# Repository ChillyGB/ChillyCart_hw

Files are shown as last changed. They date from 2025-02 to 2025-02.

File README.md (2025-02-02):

# ChillyCart (hardware)


A simple rp2350 based gameboy(color) cartdrige complete with:
- SPI SD card
- RTC 
- Accelerometer
- 8 MB of PSRAM

## ⚠️ Warning: untested design, DO NOT USE

| Parameter | Value |
|---|---|
| PCB Layers | 2 |
| Surface Finish  | ENIG(w/ gold fingers) |
| Board Thickness | 1.0mm |
| Meow | prrrr |

## TODO: 
- *Test if the design actually works and doesn't blow up*
- Route power and PSRAM/flash data lines in a cleaner way
- Provide BOM ( and cost optimize some components )

## Soures of inspiration 
- [kicad-gamepaks](https://github.com/djedditt/kicad-gamepaks) - cartrdge connector and edge cuts
- [Croco Cartridge](https://github.com/shilga/rp2040-gameboy-cartridge) - voltage translator
- [SummerCart](https://github.com/Polprzewodnikowy/SummerCart64) - RTC and power mux

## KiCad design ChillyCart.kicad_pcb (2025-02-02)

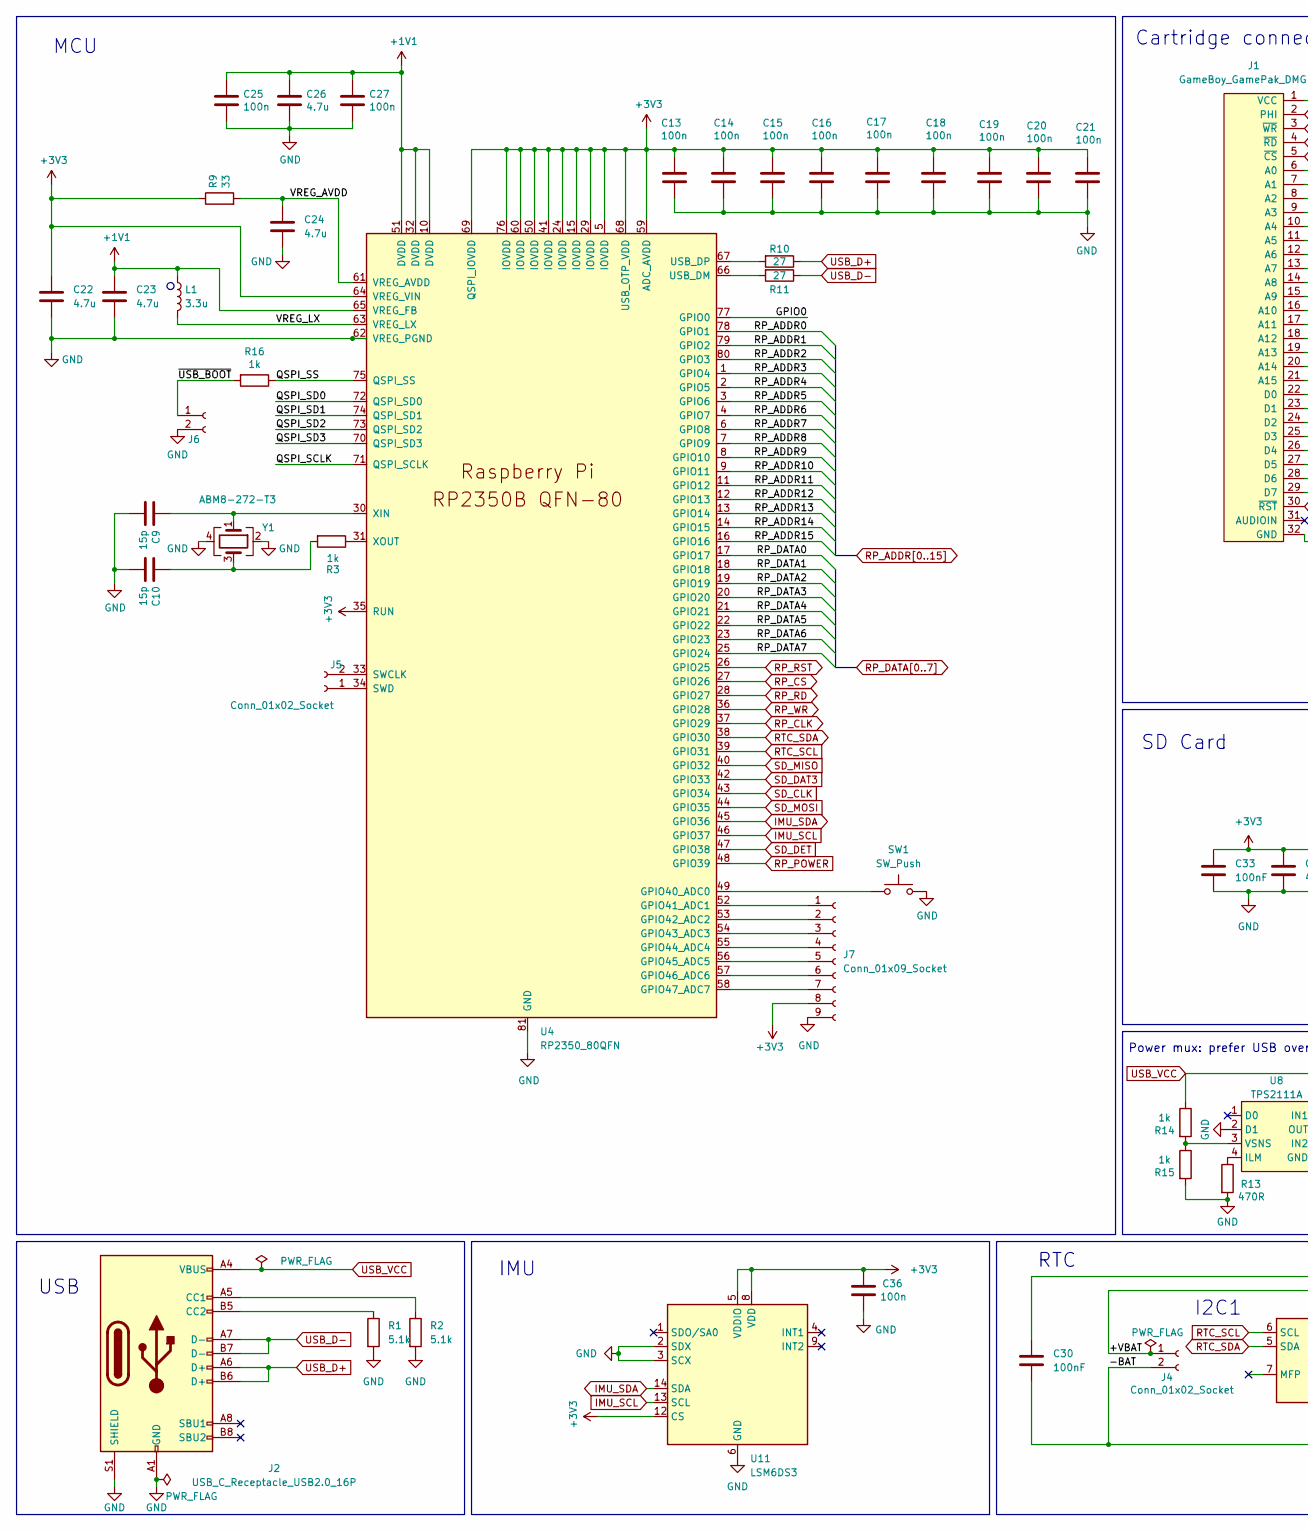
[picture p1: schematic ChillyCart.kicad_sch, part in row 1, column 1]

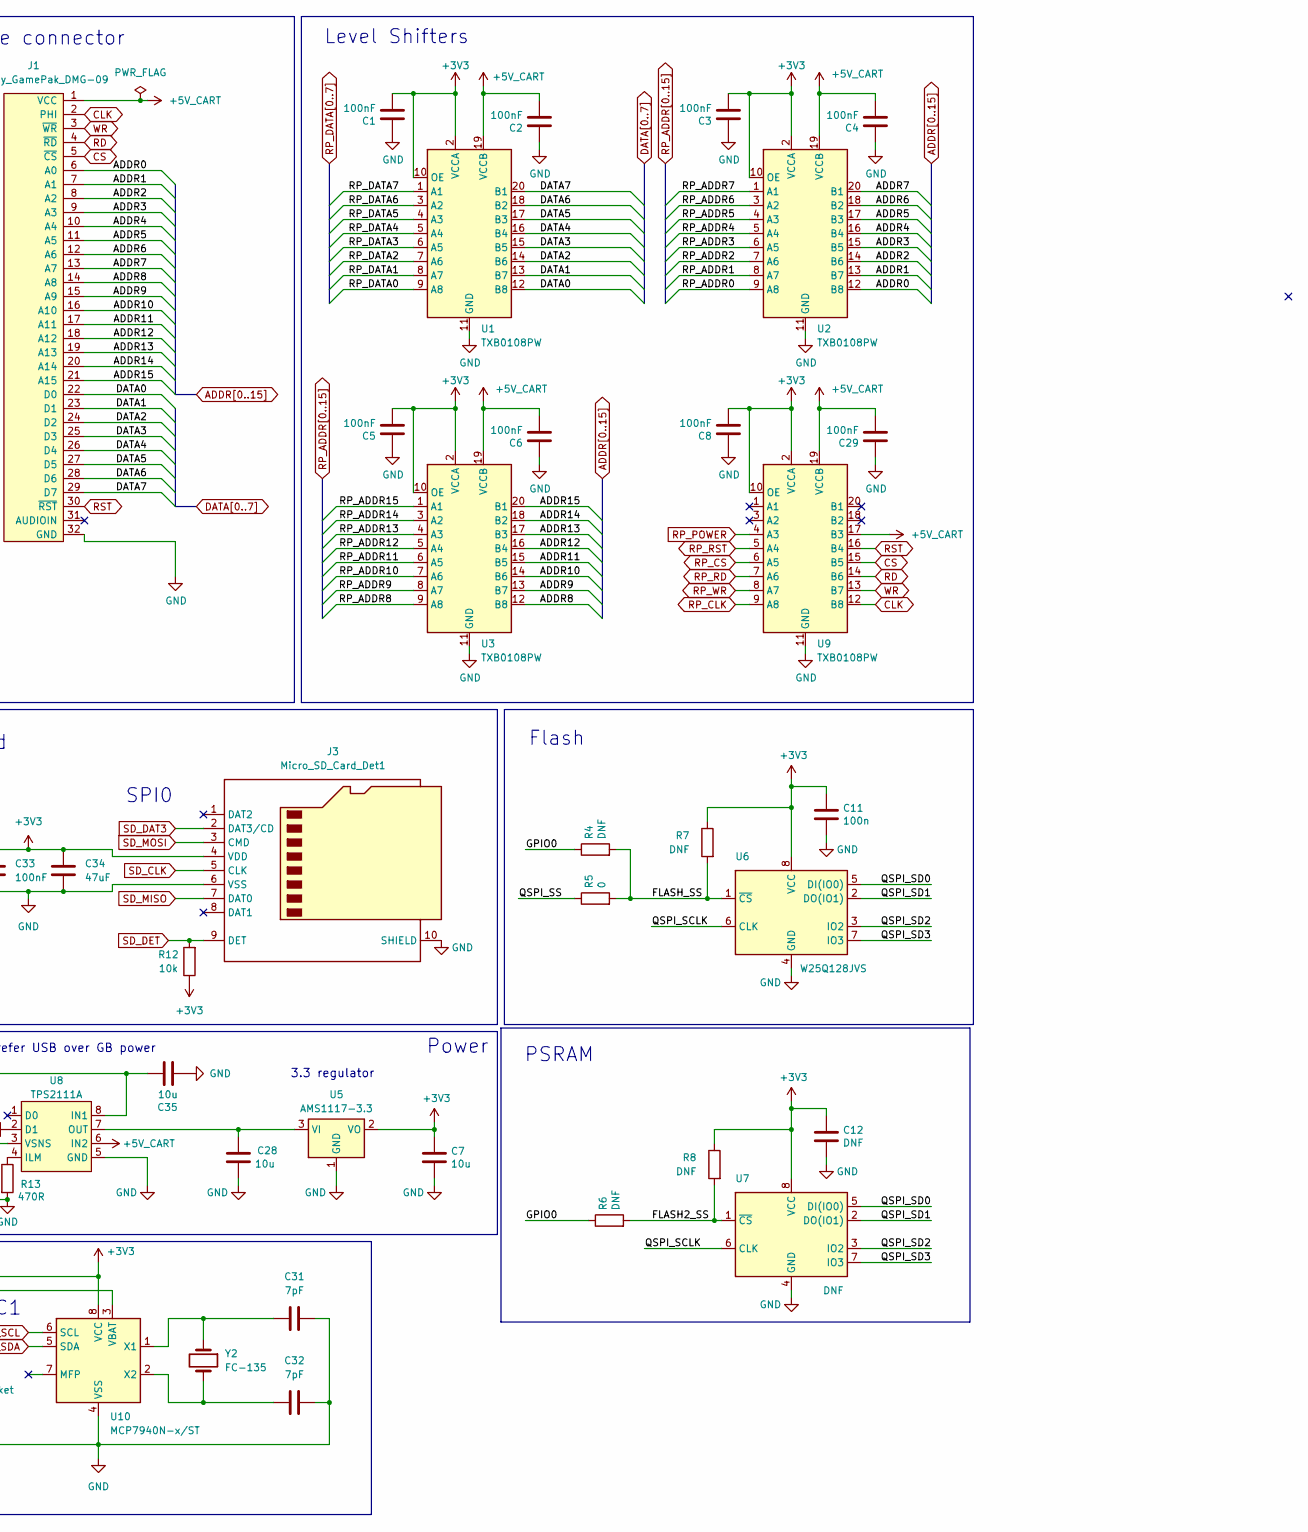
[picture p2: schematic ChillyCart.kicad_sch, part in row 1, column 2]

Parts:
C1, C2, C3, C4, C5, C6, C8, C29, C30, C33: 100nF; C_0402_1005Metric_Pad0.74x0.62mm_HandSolder
C7, C28, C35: 10u; C_0402_1005Metric_Pad0.74x0.62mm_HandSolder
C9, C10: 15p; C_0402_1005Metric_Pad0.74x0.62mm_HandSolder
C11, C13, C14, C15, C16, C17, C18, C19, C20, C21, C25, C27, C36: 100n; C_0402_1005Metric_Pad0.74x0.62mm_HandSolder
C12: DNF; C_0402_1005Metric_Pad0.74x0.62mm_HandSolder
C22, C23, C24, C26: 4.7u; C_0402_1005Metric_Pad0.74x0.62mm_HandSolder
C31, C32: 7pF; C_0402_1005Metric_Pad0.74x0.62mm_HandSolder
C34: 47uF; C_0402_1005Metric_Pad0.74x0.62mm_HandSolder
J1: GameBoy_GamePak_DMG-09; GameBoy_GamePak_DMG-09_P1.50mm_Edge
J2: USB_C_Receptacle_USB2.0_16P; USB_C_Receptacle_G-Switch_GT-USB-7010ASV
J3: Micro_SD_Card_Det1; TF-015
J4, J5, J6: Conn_01x02_Socket; TestPoint_2Pads_Pitch2.54mm_Drill0.8mm
J7: Conn_01x09_Socket; PinHeader_1x09_P1.00mm_Vertical
L1: 3.3u; L_pol_2016
R1, R2: 5.1k; R_0402_1005Metric_Pad0.72x0.64mm_HandSolder
R3, R14, R15, R16: 1k; R_0402_1005Metric_Pad0.72x0.64mm_HandSolder
R4, R6, R7, R8: DNF; R_0402_1005Metric_Pad0.72x0.64mm_HandSolder
R5: 0; R_0402_1005Metric_Pad0.72x0.64mm_HandSolder
R9: 33; R_0402_1005Metric_Pad0.72x0.64mm_HandSolder
R10, R11: 27; R_0402_1005Metric_Pad0.72x0.64mm_HandSolder
R12: 10k; R_0402_1005Metric_Pad0.72x0.64mm_HandSolder
R13: 470R; R_0402_1005Metric_Pad0.72x0.64mm_HandSolder
SW1: SW_Push; SW_Push_1P1T_XKB_TS-1187A
U1, U2, U3, U9: TXB0108PW; TSSOP-20_4.4x6.5mm_P0.65mm; LCSC C53406
U4: RP2350_80QFN; RP2350-QFN-80-1EP_10x10_P0.4mm_EP3.4x3.4mm_ThermalVias
U5: AMS1117-3.3; SOT-223-3_TabPin2
U6: W25Q128JVS; SOIC-8_5.23x5.23mm_P1.27mm
U7: DNF; SOIC-8_5.23x5.23mm_P1.27mm
U8: TPS2111A; TSSOP-8_4.4x3mm_P0.65mm
U10: MCP7940N-x/ST; TSSOP-8_4.4x3mm_P0.65mm
U11: LSM6DS3; LGA-14_3x2.5mm_P0.5mm_LayoutBorder3x4y
Y1: ABM8-272-T3; Crystal_SMD_3225-4Pin_3.2x2.5mm
Y2: FC-135; Crystal_SMD_3215-2Pin_3.2x1.5mm

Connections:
+1V1: C23.1, C25.1, C26.1, C27.1, L1.1, U4.10 (DVDD), U4.32 (DVDD), U4.51 (DVDD), U4.65 (VREG_FB)
+3V3: C1.2, C3.2, C5.2, C7.1, C8.2, C11.1, C12.1, C13.1, C14.1, C15.1, C16.1, C17.1, C18.1, C19.1, C20.1, C21.1, C22.1, C30.1, C33.1, C34.1, C36.1, J3.4 (VDD), J7.8, R7.1, R8.1, R9.1, R12.1, U1.2 (VCCA), U1.10 (OE), U2.2 (VCCA), U2.10 (OE), U3.2 (VCCA), U3.10 (OE), U4.5 (IOVDD), U4.15 (IOVDD), U4.24 (IOVDD), U4.29 (IOVDD), U4.35 (RUN), U4.41 (IOVDD), U4.50 (IOVDD), U4.59 (ADC_AVDD), U4.60 (IOVDD), U4.64 (VREG_VIN), U4.68 (USB_OTP_VDD), U4.69 (QSPI_IOVDD), U4.76 (IOVDD), U5.2 (VO), U6.8 (VCC), U7.8 (VCC), U9.2 (VCCA), U9.10 (OE), U10.8 (VCC), U11.5 (VDDIO), U11.8 (VDD), U11.12 (CS)
+5V_CART: C2.2, C4.2, C6.2, C29.2, J1.1 (VCC), U1.19 (VCCB), U2.19 (VCCB), U3.19 (VCCB), U8.6 (IN2), U9.17 (B3), U9.19 (VCCB)
/+VBAT: J4.1, U10.3 (VBAT)
/FLASH2_SS: R6.2, R8.2, U7.1 (~CS)
/FLASH_SS: R4.2, R5.2, R7.2, U6.1 (~CS)
/GPIO0: R4.1, R6.1, U4.77 (GPIO0)
/QSPI_SCLK: U4.71 (QSPI_SCLK), U6.6 (CLK), U7.6 (CLK)
/QSPI_SD0: U4.72 (QSPI_SD0), U6.5 (DI(IO0)), U7.5 (DI(IO0))
/QSPI_SD1: U4.74 (QSPI_SD1), U6.2 (DO(IO1)), U7.2 (DO(IO1))
/QSPI_SD2: U4.73 (QSPI_SD2), U6.3 (IO2), U7.3 (IO2)
/QSPI_SD3: U4.70 (QSPI_SD3), U6.7 (IO3), U7.7 (IO3)
/QSPI_SS: R5.1, R16.1, U4.75 (QSPI_SS)
/VREG_AVDD: C24.1, R9.2, U4.61 (VREG_AVDD)
/VREG_LX: L1.2, U4.63 (VREG_LX)
/~USB_BOOT: J6.1, R16.2
ADDR0: J1.6 (A0), U2.12 (B8)
ADDR1: J1.7 (A1), U2.13 (B7)
ADDR2: J1.8 (A2), U2.14 (B6)
ADDR3: J1.9 (A3), U2.15 (B5)
ADDR4: J1.10 (A4), U2.16 (B4)
ADDR5: J1.11 (A5), U2.17 (B3)
ADDR6: J1.12 (A6), U2.18 (B2)
ADDR7: J1.13 (A7), U2.20 (B1)
ADDR8: J1.14 (A8), U3.12 (B8)
ADDR9: J1.15 (A9), U3.13 (B7)
ADDR10: J1.16 (A10), U3.14 (B6)
ADDR11: J1.17 (A11), U3.15 (B5)
ADDR12: J1.18 (A12), U3.16 (B4)
ADDR13: J1.19 (A13), U3.17 (B3)
ADDR14: J1.20 (A14), U3.18 (B2)
ADDR15: J1.21 (A15), U3.20 (B1)
CLK: J1.2 (PHI), U9.12 (B8)
CS: J1.5 (~CS), U9.15 (B5)
DATA0: J1.22 (D0), U1.12 (B8)
DATA1: J1.23 (D1), U1.13 (B7)
DATA2: J1.24 (D2), U1.14 (B6)
DATA3: J1.25 (D3), U1.15 (B5)
DATA4: J1.26 (D4), U1.16 (B4)
DATA5: J1.27 (D5), U1.17 (B3)
DATA6: J1.28 (D6), U1.18 (B2)
DATA7: J1.29 (D7), U1.20 (B1)
GND: C1.1, C2.1, C3.1, C4.1, C5.1, C6.1, C7.2, C8.1, C9.2, C10.2, C11.2, C12.2, C13.2, C14.2, C15.2, C16.2, C17.2, C18.2, C19.2, C20.2, C21.2, C22.2, C23.2, C24.2, C25.2, C26.2, C27.2, C28.2, C29.1, C30.2, C31.2, C32.1, C33.2, C34.2, C35.2, C36.2, J1.32 (GND), J2.A1 (GND), J2.A12 (GND), J2.B1 (GND), J2.B12 (GND), J2.S1 (SHIELD), J3.6 (VSS), J3.10 (SHIELD), J4.2, J6.2, J7.9, R1.2, R2.2, R13.2, R15.2, SW1.2, U1.11 (GND), U2.11 (GND), U3.11 (GND), U4.62 (VREG_PGND), U4.81 (GND), U5.1 (GND), U6.4 (GND), U7.4 (GND), U8.2 (D1), U8.5 (GND), U9.11 (GND), U10.4 (VSS), U11.2 (SDX), U11.3 (SCX), U11.6 (GND), U11.7 (GND), Y1.2, Y1.4
IMU_SCL: U4.46 (GPIO37), U11.13 (SCL)
IMU_SDA: U4.45 (GPIO36), U11.14 (SDA)
unnamed: C10.1, R3.2, Y1.3
unnamed: J2.A5 (CC1), R2.1
unnamed: J2.B5 (CC2), R1.1
unnamed: J5.1, U4.34 (SWD)
unnamed: J5.2, U4.33 (SWCLK)
unnamed: J7.1, U4.52 (GPIO41_ADC1)
unnamed: J7.2, U4.53 (GPIO42_ADC2)
unnamed: J7.3, U4.54 (GPIO43_ADC3)
unnamed: J7.4, U4.55 (GPIO44_ADC4)
unnamed: J7.5, U4.56 (GPIO45_ADC5)
unnamed: J7.6, U4.57 (GPIO46_ADC6)
unnamed: J7.7, U4.58 (GPIO47_ADC7)
unnamed: SW1.1, U4.49 (GPIO40_ADC0)
unnamed: R11.2, U4.66 (USB_DM)
unnamed: R10.2, U4.67 (USB_DP)
unnamed: C9.1, U4.30 (XIN), Y1.1
unnamed: R3.1, U4.31 (XOUT)
unnamed: C28.1, U5.3 (VI), U8.7 (OUT)
unnamed: R13.1, U8.4 (ILM)
unnamed: R14.2, R15.1, U8.3 (VSNS)
unnamed: C31.1, U10.1 (X1), Y2.1
unnamed: C32.2, U10.2 (X2), Y2.2
RD: J1.4 (~RD), U9.14 (B6)
RP_ADDR0: U2.9 (A8), U4.78 (GPIO1)
RP_ADDR1: U2.8 (A7), U4.79 (GPIO2)
RP_ADDR2: U2.7 (A6), U4.80 (GPIO3)
RP_ADDR3: U2.6 (A5), U4.1 (GPIO4)
RP_ADDR4: U2.5 (A4), U4.2 (GPIO5)
RP_ADDR5: U2.4 (A3), U4.3 (GPIO6)
RP_ADDR6: U2.3 (A2), U4.4 (GPIO7)
RP_ADDR7: U2.1 (A1), U4.6 (GPIO8)
RP_ADDR8: U3.9 (A8), U4.7 (GPIO9)
RP_ADDR9: U3.8 (A7), U4.8 (GPIO10)
RP_ADDR10: U3.7 (A6), U4.9 (GPIO11)
RP_ADDR11: U3.6 (A5), U4.11 (GPIO12)
RP_ADDR12: U3.5 (A4), U4.12 (GPIO13)
RP_ADDR13: U3.4 (A3), U4.13 (GPIO14)
RP_ADDR14: U3.3 (A2), U4.14 (GPIO15)
RP_ADDR15: U3.1 (A1), U4.16 (GPIO16)
RP_CLK: U4.37 (GPIO29), U9.9 (A8)
RP_CS: U4.27 (GPIO26), U9.6 (A5)
RP_DATA0: U1.9 (A8), U4.17 (GPIO17)
RP_DATA1: U1.8 (A7), U4.18 (GPIO18)
RP_DATA2: U1.7 (A6), U4.19 (GPIO19)
RP_DATA3: U1.6 (A5), U4.20 (GPIO20)
RP_DATA4: U1.5 (A4), U4.21 (GPIO21)
RP_DATA5: U1.4 (A3), U4.22 (GPIO22)
RP_DATA6: U1.3 (A2), U4.23 (GPIO23)
RP_DATA7: U1.1 (A1), U4.25 (GPIO24)
RP_POWER: U4.48 (GPIO39), U9.4 (A3)
RP_RD: U4.28 (GPIO27), U9.7 (A6)
RP_RST: U4.26 (GPIO25), U9.5 (A4)
RP_WR: U4.36 (GPIO28), U9.8 (A7)
RST: J1.30 (~RST), U9.16 (B4)
RTC_SCL: U4.39 (GPIO31), U10.6 (SCL)
RTC_SDA: U4.38 (GPIO30), U10.5 (SDA)
SD_CLK: J3.5 (CLK), U4.43 (GPIO34)
SD_DAT3: J3.2 (DAT3/CD), U4.42 (GPIO33)
SD_DET: J3.9 (DET), R12.2, U4.47 (GPIO38)
SD_MISO: J3.7 (DAT0), U4.40 (GPIO32)
SD_MOSI: J3.3 (CMD), U4.44 (GPIO35)
USB_D+: J2.A6 (D+), J2.B6 (D+), R10.1
USB_D-: J2.A7 (D-), J2.B7 (D-), R11.1
USB_VCC: C35.1, J2.A4 (VBUS), J2.A9 (VBUS), J2.B4 (VBUS), J2.B9 (VBUS), R14.1, U8.8 (IN1)
WR: J1.3 (~WR), U9.13 (B7)

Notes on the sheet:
Level Shifters
I2C1
3.3 regulator
Power mux: prefer USB over GB power
Power
SPI0
SD Card
Cartridge connector
RTC
USB
IMU
Flash
MCU
PSRAM

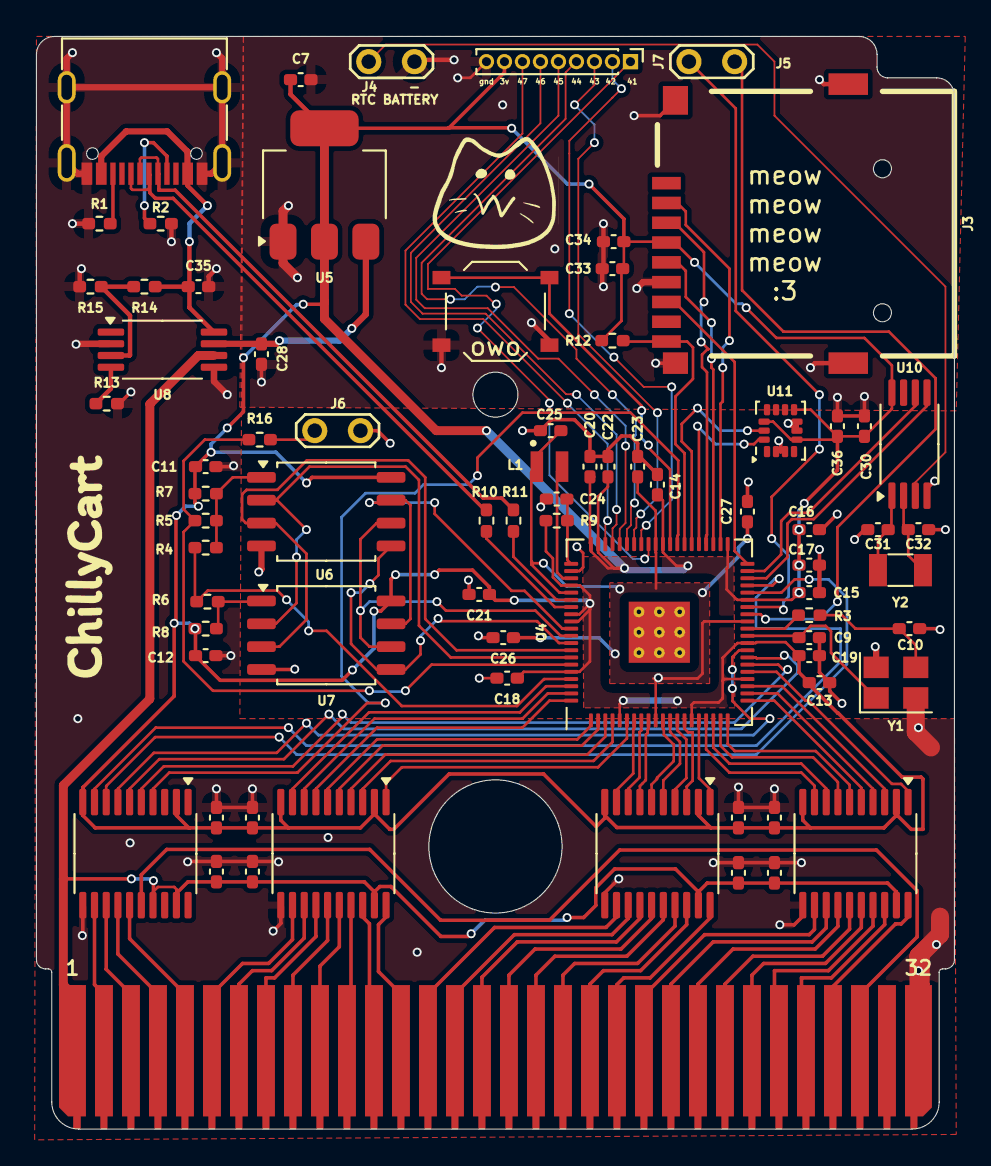
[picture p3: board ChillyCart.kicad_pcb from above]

Board: 2 copper layers, 51.0 x 60.7 mm, 74 parts (0 on the bottom side), 110 nets.

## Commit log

2025-01-22 Inital commit
    [ChillyCart.kicad_pcb, ChillyCart.kicad_sch, ChillyCart.sch]
2025-01-22 Added psram,flash,rtc,sd
    [ChillyCart.kicad_pcb, ChillyCart.kicad_sch]
2025-01-23 Add IMU, power mux and cleanup schematic
    [ChillyCart.kicad_pcb, ChillyCart.kicad_sch]
2025-01-24 Add debug connectors and push button, fix ERC errors
    [ChillyCart.kicad_sch]
2025-01-24 Initial routing
    [ChillyCart.kicad_pcb, ChillyCart.kicad_sch]
2025-01-25 Finish routingn
    [ChillyCart.kicad_pcb, ChillyCart.kicad_sch]
2025-01-26 Tidy up silkscreen
    [ChillyCart.kicad_pcb]
2025-02-02 jlc gerber export settings
    [ChillyCart.kicad_pcb]
